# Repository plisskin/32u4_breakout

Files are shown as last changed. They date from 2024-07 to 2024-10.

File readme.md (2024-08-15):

# Atmega32U4 Breakout Board

This is a simple breakout board for the Atmega32U4 microcontroller.  It brings out all of the pins to headers and also provides places for a crystal resonator and an ICSP programming header.  

All of the power pins route to the top of the board where power can be connected in a single spot and all of the ground pins route to the bottom of the board where ground can be connected in a single spot.  The intention is to use jumpers to connect the power/ground pins to the power/ground 'header'.

Created using KiCad 8 and routed using freerouter.

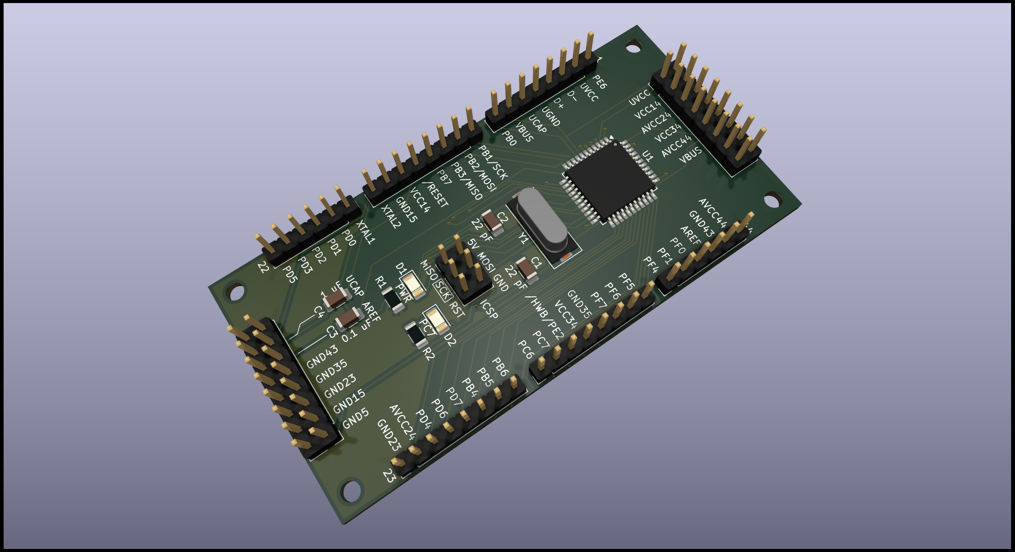
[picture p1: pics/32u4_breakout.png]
PCB


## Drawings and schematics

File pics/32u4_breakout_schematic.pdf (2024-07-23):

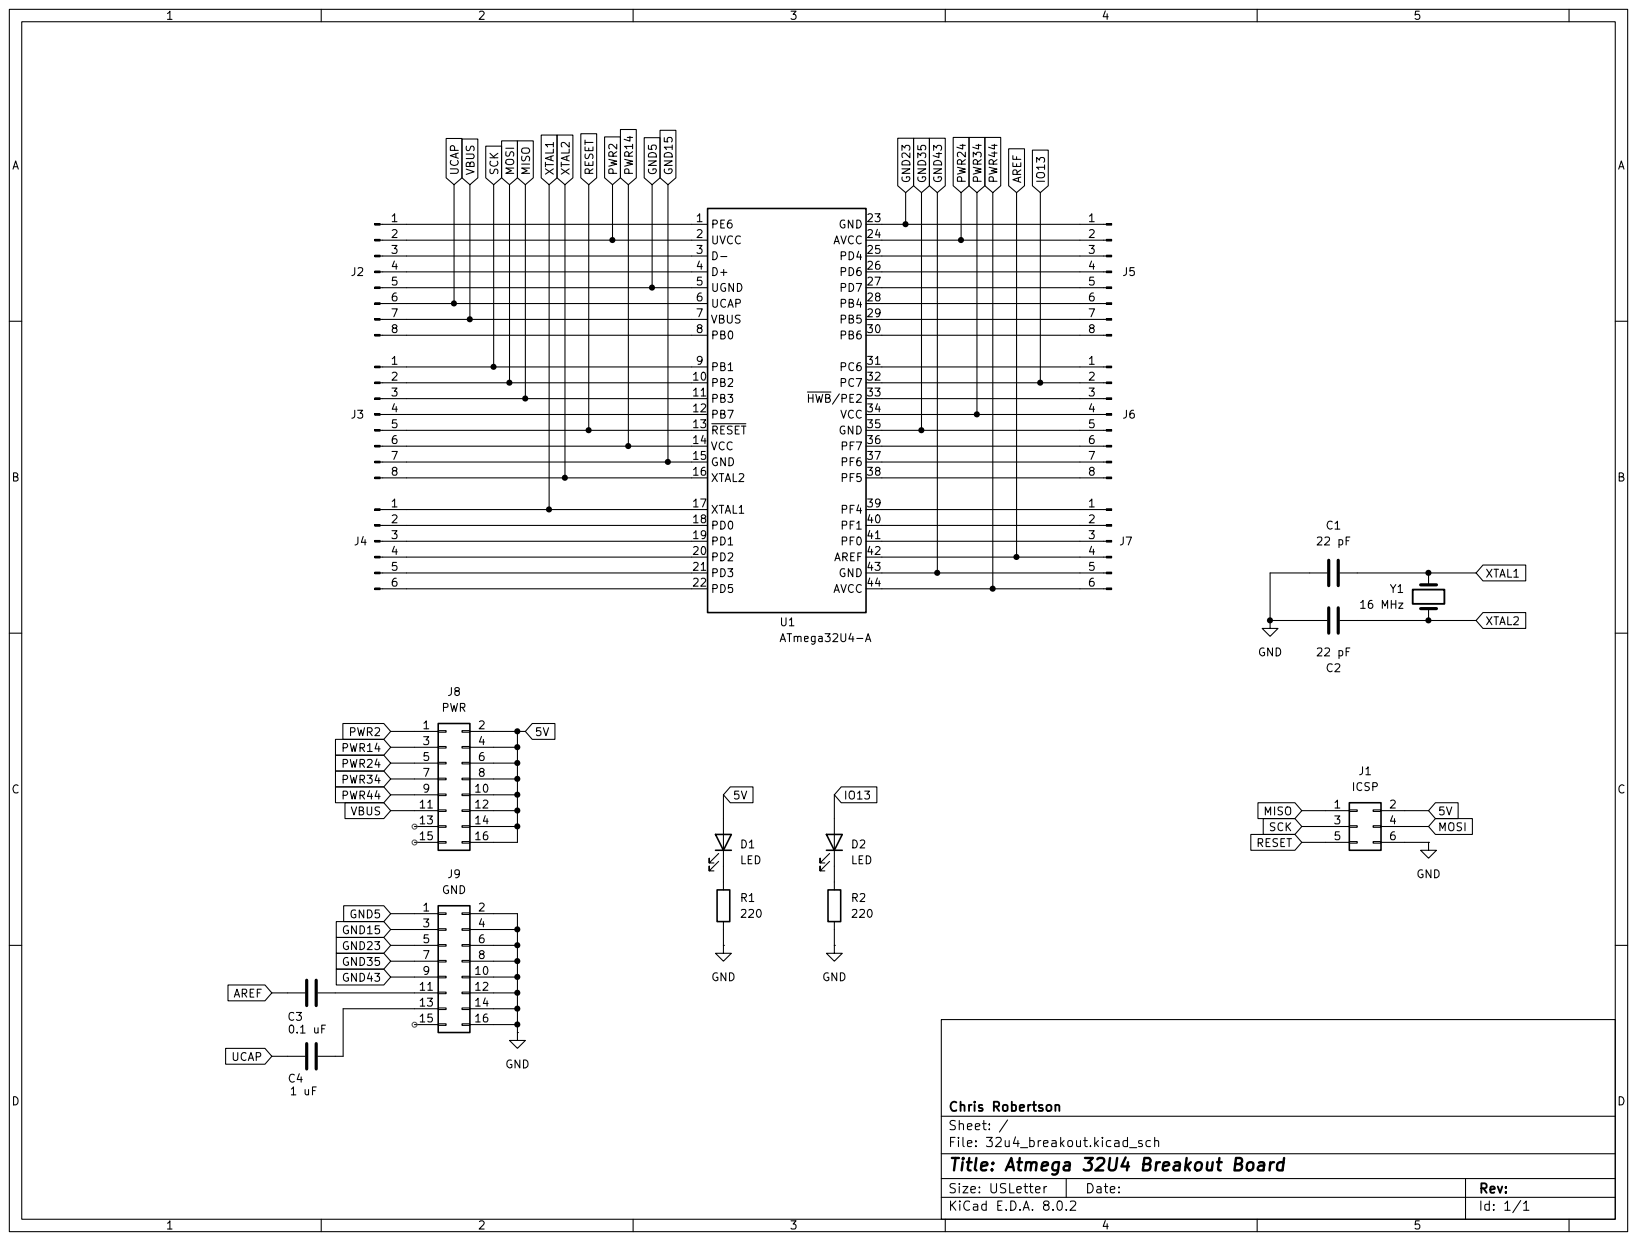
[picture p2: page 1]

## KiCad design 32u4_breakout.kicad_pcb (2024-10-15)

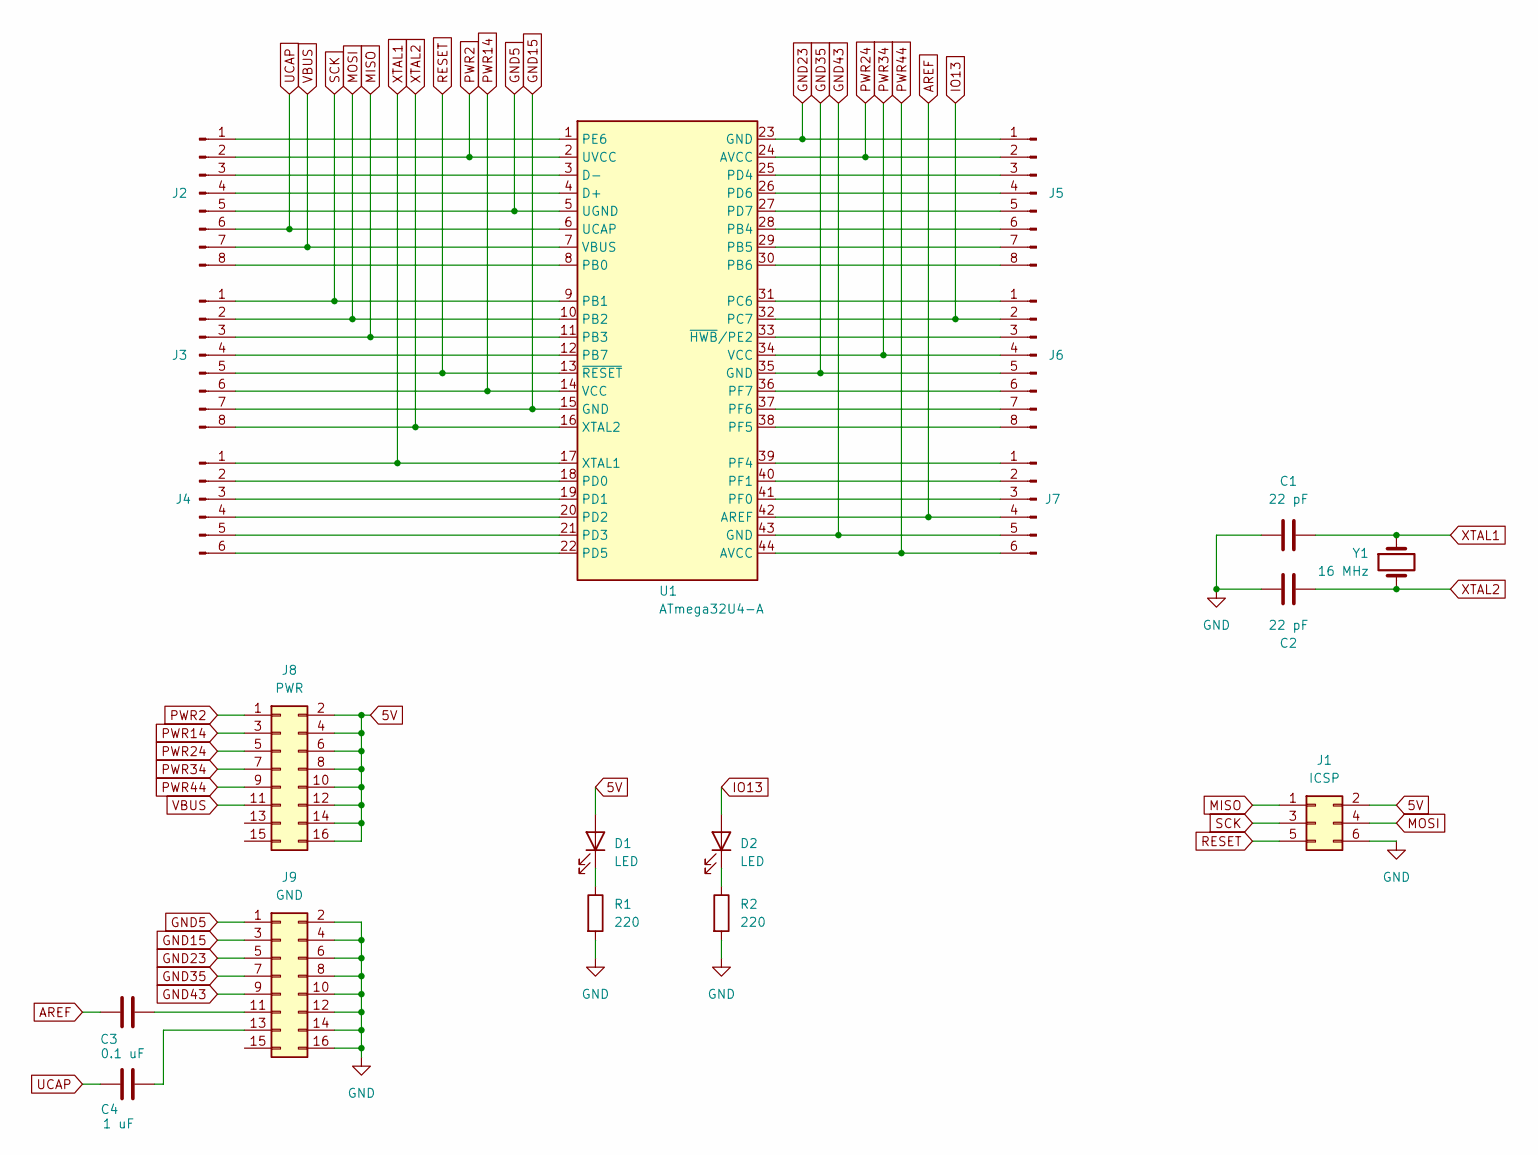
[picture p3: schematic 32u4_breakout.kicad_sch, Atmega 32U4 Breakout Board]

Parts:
C1, C2: 22 pF; C_1206_3216Metric; Manufacturer Part C1206C220J5GAC7800
C3: 0.1 uF; C_1206_3216Metric; Manufacturer Part C1206C104J5RAC7025
C4: 1 uF; C_1206_3216Metric; Manufacturer Part C1206C105K4RAC7800
D1, D2: LED; LED_1206_3216Metric
J1: ICSP; PinHeader_2x03_P2.54mm_Vertical; Manufacturer Part 0751020041
J2, J3, J5, J6: PinHeader_1x08_P2.54mm_Vertical
J4, J7: PinHeader_1x06_P2.54mm_Vertical
J8: PWR; PinHeader_2x08_P2.54mm_Vertical
J9: GND; PinHeader_2x08_P2.54mm_Vertical
R1, R2: 220; R_1206_3216Metric
U1: ATmega32U4-A; TQFP-44_10x10mm_P0.8mm; Manufacturer Part ATMEGA32U4-AU
Y1: 16 MHz; Crystal_SMD_HC49-SD; Manufacturer Part 830034122

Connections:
5V: D1.2 (A), J1.2, J8.2, J8.4, J8.6, J8.8, J8.10, J8.12, J8.14, J8.16
AREF: C3.1, J7.4, U1.42 (AREF)
GND: C1.2, C2.2, J1.6, J9.2, J9.4, J9.6, J9.8, J9.10, J9.12, J9.14, J9.16, R1.2, R2.2
GND5: J2.5, J9.1, U1.5 (UGND)
GND15: J3.7, J9.3, U1.15 (GND)
GND23: J5.1, J9.5, U1.23 (GND)
GND35: J6.5, J9.7, U1.35 (GND)
GND43: J7.5, J9.9, U1.43 (GND)
IO13: D2.2 (A), J6.2, U1.32 (PC7)
MISO: J1.1, J3.3, U1.11 (PB3)
MOSI: J1.4, J3.2, U1.10 (PB2)
unnamed: D1.1 (K), R1.1
unnamed: D2.1 (K), R2.1
unnamed: J2.1, U1.1 (PE6)
unnamed: J2.3, U1.3 (D-)
unnamed: J2.4, U1.4 (D+)
unnamed: J2.8, U1.8 (PB0)
unnamed: J3.4, U1.12 (PB7)
unnamed: J4.2, U1.18 (PD0)
unnamed: J4.3, U1.19 (PD1)
unnamed: J4.4, U1.20 (PD2)
unnamed: J4.5, U1.21 (PD3)
unnamed: J4.6, U1.22 (PD5)
unnamed: J5.3, U1.25 (PD4)
unnamed: J5.4, U1.26 (PD6)
unnamed: J5.5, U1.27 (PD7)
unnamed: J5.6, U1.28 (PB4)
unnamed: J5.7, U1.29 (PB5)
unnamed: J5.8, U1.30 (PB6)
unnamed: J6.1, U1.31 (PC6)
unnamed: J6.3, U1.33 (~HWB/PE2)
unnamed: J6.6, U1.36 (PF7)
unnamed: J6.7, U1.37 (PF6)
unnamed: J6.8, U1.38 (PF5)
unnamed: J7.1, U1.39 (PF4)
unnamed: J7.2, U1.40 (PF1)
unnamed: J7.3, U1.41 (PF0)
unnamed: C3.2, J9.11
unnamed: C4.1, J9.13
PWR2: J2.2, J8.1, U1.2 (UVCC)
PWR14: J3.6, J8.3, U1.14 (VCC)
PWR24: J5.2, J8.5, U1.24 (AVCC)
PWR34: J6.4, J8.7, U1.34 (VCC)
PWR44: J7.6, J8.9, U1.44 (AVCC)
RESET: J1.5, J3.5, U1.13 (~RESET)
SCK: J1.3, J3.1, U1.9 (PB1)
UCAP: C4.2, J2.6, U1.6 (UCAP)
VBUS: J2.7, J8.11, U1.7 (VBUS)
XTAL1: C1.1, J4.1, U1.17 (XTAL1), Y1.1
XTAL2: C2.1, J3.8, U1.16 (XTAL2), Y1.2

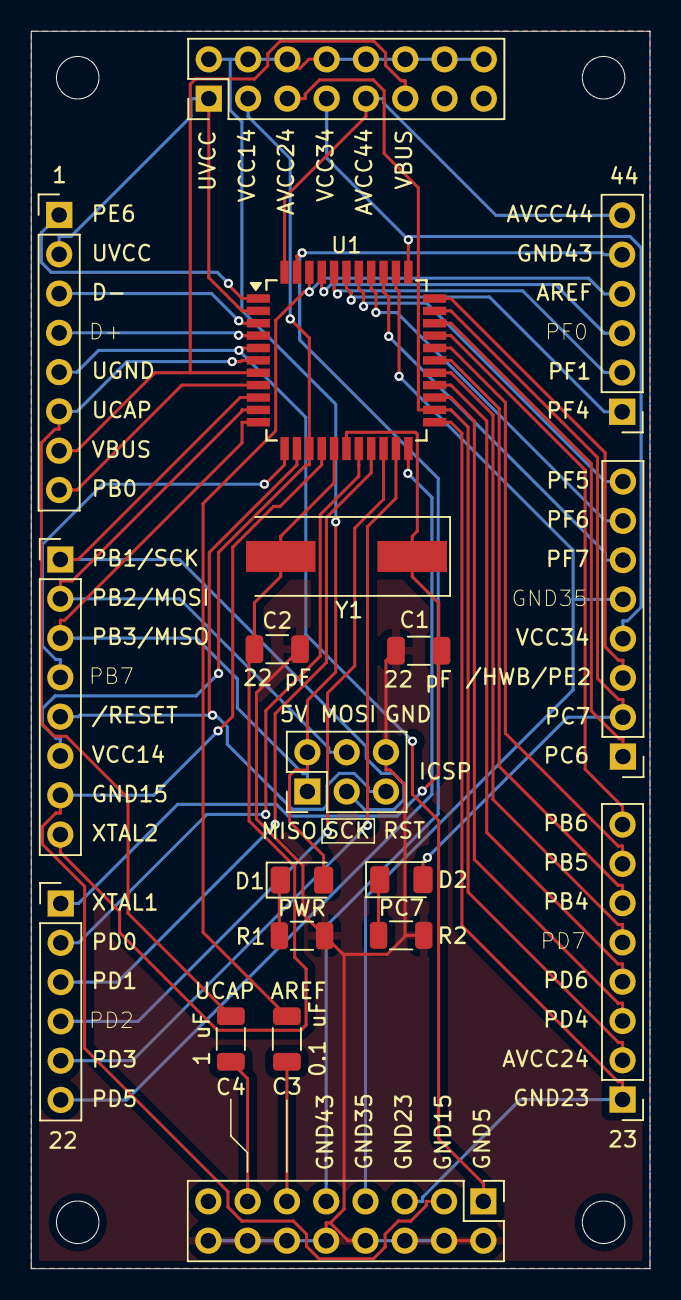
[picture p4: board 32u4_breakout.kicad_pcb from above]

Board: 2 copper layers, 40.0 x 80.0 mm, 19 parts (0 on the bottom side), 50 nets.

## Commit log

2024-07-23 Added LED for power and PC7/IO13
    [32u4_breakout-B_Cu.gbr, 32u4_breakout-B_Mask.gbr, 32u4_breakout-B_Paste.gbr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]
2024-08-15 Added pcb picture to readme.md
2024-10-15 Fixed routing (missing grounds)
    [32u4_breakout-B_Cu.gbr, 32u4_breakout-B_Mask.gbr, 32u4_breakout-B_Paste.gbr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]
